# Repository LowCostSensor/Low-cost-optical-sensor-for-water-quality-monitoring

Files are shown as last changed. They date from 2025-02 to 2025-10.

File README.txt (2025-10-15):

Additional details on calibration and analytical performance:
Cirrone, R. G., Boldrini, A., Polvani, A., Arrigucci, M., Liu, X., Galgani, L., Woods, S., & Loiselle, S. A. (2025). Low-Cost Optical Sensing for Nitrate and Phosphate: Advancing Community Freshwater Monitoring. ACS ES&T Water.
https://doi.org/10.1021/acsestwater.5c00314

## License

This project is licensed under the GNU General Public License v3.0 (GPLv3).  
See the LICENSE file for details.

A portable, low-cost optical sensor for community-based monitoring of nitrates and orthophosphates in freshwater were developed. Its analytical performance and reliability were demonstrated in both laboratory conditions and the intended operational environment, with all components fully integrated. This achievement corresponds to a technological readiness level of 7-8. All necessary information for reproducing the sensor, including a 3D CAD model, software, and a user guide for setup and usage, has been made open-source. The same colorimetric kits employed in this study are currently utilized in 110 active citizen science projects across Europe and Africa. By improving the accuracy of these colorimetric kits, the proposed instrument has the potential to empower citizen science monitoring, breaking barriers to data integration between environmental agencies and community-driven monitoring. Nonetheless, further durability testing and inter-project validation could enhance the sensor’s reliability. Future work will focus on integrating fluorescence measurements, scattering correction, multispectral capabilities, and app-based functionality to expand the sensor’s applications and usability.

COMING SOON
Automatic data shared online.

For any information contact steven.loiselle@unisi.it // riccardogaetano.cirrone@unipa.it // amedeo.boldrini3@unisi.it // alessio.polvani@student.unisi.it

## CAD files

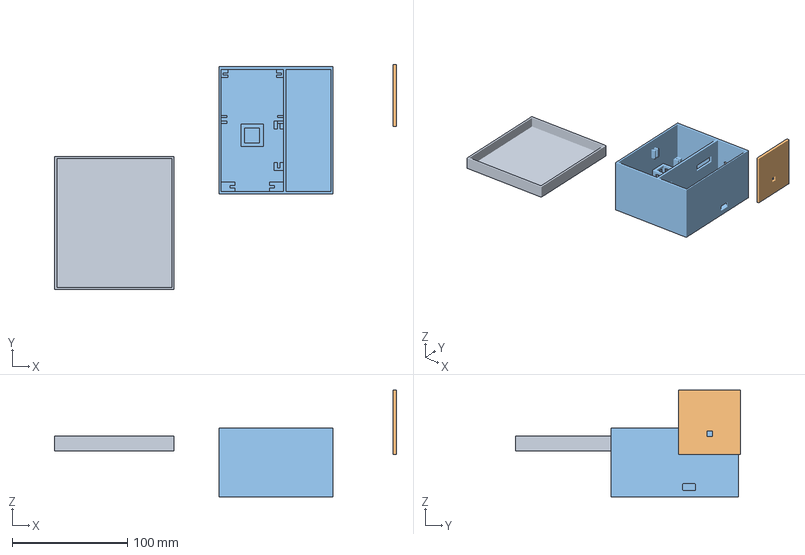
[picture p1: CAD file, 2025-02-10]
3D_CAD/Low_cost_optical_sensor_box_3D_CAD.3mf
297.3 x 196.0 x 92.8 mm
Cover
Fenditura
Main box

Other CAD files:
3D_CAD/Low_cost_optical_sensor_3D_CAD.stl

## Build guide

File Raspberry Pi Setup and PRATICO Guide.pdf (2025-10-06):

Raspberry Pi Terminal Setup & PRATICO Instrument Guide

1. First Boot and Login
- Connect Raspberry Pi to a monitor via mini HDMI and connect a keyboard.
- Power on the Raspberry Pi.
- Default login (Raspberry Pi OS):

Username: pi
Password: raspberry
- You will see the terminal prompt:

pi@raspberrypi:~$

2. Configure Wi-Fi using wpa_supplicant
1. Edit the wpa_supplicant file:

sudo nano /etc/wpa_supplicant/wpa_supplicant.conf
2. Add your network credentials:

country=US
ctrl_interface=DIR=/var/run/wpa_supplicant GROUP=netdev update_config=1

network={
ssid="YOUR_SSID"
psk="YOUR_PASSWORD"
}
3. Save (CTRL+O) and exit (CTRL+X).
4. Apply changes:

sudo wpa_cli reconfigure
5. Check your IP:

ip a

3. Enable SSH for Remote Access
1. Enable and start SSH:

sudo systemctl enable ssh
sudo systemctl start ssh
2. Find Pi’s IP:

hostname -I
3. Connect from another computer:

ssh pi@<IP_ADDRESS>

4. Wiring for FWW_user.py
- Green LED (light source): GPIO 26 -> Positive, GND -> Negative
- Red LED (working/not ready): GPIO 23 -> Positive, GND -> Negative
- Ready LED (green): GPIO 24 -> Positive, GND -> Negative
- Button: GPIO 4 -> Button -> GND
- I2C Sensor (LTR329): SDA -> SDA, SCL -> SCL, 3.3V -> VCC, GND -> GND
5. Python Script Overview (FWW_user.py and Calibration)
Purpose: Automates water analysis for N-NO3 and P-PO4 using LED light measurements and allows sensor calibration.
Initialization: - Setup GPIO, button, and I2C sensor. - Load calibration files (P_cal.txt,
N_cal.txt).
Key Functions: - lux_conversion(): Converts raw sensor data to lux. - LED_on(): Turns green LED on and records light readings. - simple_measure(): Measures ambient + LED light. -blank(): Blank measurement for reference. - measure(): Measures analyte sample. -concentration(): Converts absorbance to concentration. - save(): Saves results with timestamp. - Offline storage: Each measurement is automatically saved as a .txt file in /home/pa/ with a timestamp and analyte identifier (e.g., 2025_10_06_14_30_NNO3.txt). This allows offline access to results without network or database connection. - Nitrates() and Phosphates(): Handles analyte measurement logic. - NNO3_calibration() and PPO4_calibration(): Guides calibration using standard solutions. - linear_fitting(): Calculates calibration slope, intercept, and R^2. - main(): Controls loop and LED/button interactions.
Workflow: 1. Blank measurement at startup. 2. Loop: - Red LED blares. - Wait 10s for button press: - Pressed -> N-NO3 measurement. - Not pressed -> P-PO4 measurement. - Results are saved automatically offline as .txt files in /home/pa/. 3. Calibration guides user through known concentration standards and saves results to file.

6. ABC of Linux Terminal Commands Command Meaning
ls | List files
cd | Change directory
pwd | Print working directory
nano | Text editor
sudo | Execute as admin
chmod | Change file permissions
systemctl Manage services
reboot | Restart Pi
ip a | Show network interfaces
ssh | Secure remote login
7. Auto-run Script at Boot (Before Login)
1. Edit rc.local:

sudo nano /etc/rc.local
2. Add above exit 0:

python3 /home/pi/FWW_user.py &
3. Save and exit. The script will run on boot before login.
8. Python Requirements
Requirements.txt:

rpi.gpio
adafruit-circuitpython-ltr329-ltr303 numpy
pandas
scikit-learn
gpiozero
Installation (system-wide, no virtual environment):

sudo apt update
sudo apt install python3-pip -y
sudo pip3 install -r /home/pi/requirements.txt
This will install all required libraries for both the main instrument script and calibration script.

9. Move Files In/Out using SCP
Copy file from local machine to Raspberry Pi:

scp /path/to/local/file pi@<IP_ADDRESS>:/home/pi/
Copy file from Raspberry Pi to local machine:

scp pi@<IP_ADDRESS>:/home/pi/file.txt /path/to/local/destination/

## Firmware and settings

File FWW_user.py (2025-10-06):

"""
Author: Riccardo G. Cirrone
Last Update: Oct 2025

Field Guidelines for Water Analysis Instrument:
    1. Ensure calibration files (P_cal.txt and N_cal.txt) are present.
    2. Power on instrument; the green LED will turn on (ready for the blank).
    3. Press the button to perform the blank measurement (using distilled water).
    4. After the blank, the red LED will blink indicating the system is ready:
       - Wait 10 seconds without pressing --> P-PO4 mode
       - Press the button within 10 seconds --> N-NO3 mode
    5. In N-NO3 mode the green LED will blink
    6. Results are automatically saved to a timestamped .txt file
    7. After each measurement, the red LED blares again and the system is ready to choose the analyte again
"""

import time
import board
import adafruit_ltr329_ltr303 as adafruit_ltr329
import RPi.GPIO as GPIO
from datetime import datetime, timedelta
import pandas as pd
from gpiozero import Button as bt
import numpy as np
import threading

# --- Setup LEDs ---
GPIO.setmode(GPIO.BCM)
GPIO.setwarnings(False)
GPIO.setup(26, GPIO.OUT)  # Green LED (light source)
GPIO.setup(23, GPIO.OUT)  # Red LED (working/not ready)
GPIO.setup(24, GPIO.OUT)  # Green LED (ready)

# --- Setup button ---
button = bt(4, pull_up=True)
red_led_running = False
green_led_running = False

# --- Setup sensor ---
i2c = board.I2C()
time.sleep(0.5)
ltr329 = adafruit_ltr329.LTR329(i2c)

# --- Sensor parameters ---
ltr329.als_gain = 96
ALS_gain = ltr329.als_gain
ltr329.integration_time = 400
ALS_int = ltr329.integration_time
ltr329.measurement_rate = 2000
ALS_rate = ltr329.measurement_rate

print("WORKING PARAMETERS\n",
      f"GAIN = {ALS_gain}\n",
      f"Integration Time = {ALS_int}\n",
      f"Measurement Rate = {ALS_rate}\n")

# --- Load calibration ---
def get_calibration():
    P = open("/home/pa/P_cal.txt")
    P_content = P.readlines()
    P.close()
    P_R2 = float(P_content[6])
    P_slope = float(P_content[7])
    P_intercept = float(P_content[8])

    N = open("/home/pa/N_cal.txt")
    N_content = N.readlines()
    N.close()
    N_R2 = float(N_content[6])
    N_slope = float(N_content[7])
    N_intercept = float(N_content[8])

    return P_R2, P_slope, P_intercept, N_R2, N_slope, N_intercept

P_R2, P_slope, P_intercept, N_R2, N_slope, N_intercept = get_calibration()

# --- Global variables ---
values = []
blank_value = []

# --- Lux conversion ---
def lux_conversion():
    CH0, CH1 = ltr329.light_channels
    try:
        ratio = CH1 / (CH0 + CH1 + 1e-7)  # avoid division by zero
        if ratio < 0.45:
            ALS_lux = (1.7743 * CH0 + 1.1059 * CH1) / ALS_gain / ALS_int
        elif 0.45 <= ratio < 0.64:
            ALS_lux = (4.2785 * CH0 - 1.9548 * CH1) / ALS_gain / ALS_int
        elif 0.64 <= ratio < 0.85:
            ALS_lux = (0.5926 * CH0 + 0.1185 * CH1) / ALS_gain / ALS_int
        else:
            ALS_lux = 1e-5
    except ZeroDivisionError:
        ALS_lux = 0
    return ALS_lux

# --- LED control ---
def LED_on():
    GPIO.output(26, GPIO.HIGH)
    stop = datetime.now() + timedelta(seconds=2)
    while datetime.now() <= stop:
        lux = round(lux_conversion(),4)
        print(lux)
        values.append(lux)
        time.sleep(0.5)
    GPIO.output(26, GPIO.LOW)

def passive():
    stop = datetime.now() + timedelta(seconds=3)
    while datetime.now() <= stop:
        lux = round(lux_conversion(),4)
        print(lux)
        values.append(lux)
        time.sleep(0.5)

def simple_measure():
    passive()
    LED_on()
    passive()

# --- LED blinking ---
def ready_on():
    GPIO.output(24, GPIO.HIGH)

def ready_off():
    GPIO.output(24, GPIO.LOW)

def working_on():
    GPIO.output(23, GPIO.HIGH)

def working_off():
    GPIO.output(23, GPIO.LOW)

def blare_red():
    global red_led_running
    red_led_running = True
    while red_led_running:
        GPIO.output(23, GPIO.HIGH)
        time.sleep(0.5)
        GPIO.output(23, GPIO.LOW)
        time.sleep(0.5)

def stop_blare_red():
    global red_led_running
    red_led_running = False

def blare_green():
    global green_led_running
    green_led_running = True
    while green_led_running:
        GPIO.output(24, GPIO.HIGH)
        time.sleep(0.5)
        GPIO.output(24, GPIO.LOW)
        time.sleep(0.5)

def stop_blare_green():
    global green_led_running
    green_led_running = False

# --- Measurement functions ---
def blank():
    ready_on()
    button.wait_for_press()
    ready_off()
    working_on()
    simple_measure()
    working_off()
    try:
        b = max(values)
    except ValueError:
        b = 0
    blank_value.append(b)
    values.clear()

def measure():
    stop_blare_red()
    stop_blare_green()
    time.sleep(0.5)
    ready_on()
    button.wait_for_press()
    ready_off()
    working_on()
    simple_measure()
    working_off()
    try:
        A = round(-np.log10((max(values)-0.0004)/(max(blank_value)-0.0004)),4)
    except (ZeroDivisionError, ValueError):
        A = 0
    values.clear()
    GPIO.output(26, GPIO.LOW)
    return A

def concentration(absorbance, analyte):
    if analyte == 'N':
        if N_slope != 0:
            c = (absorbance - N_intercept) / N_slope
        else:
            c = 0
    elif analyte == 'P':
        if P_slope != 0:
            c = (absorbance - P_intercept) / P_slope
        else:
            c = 0
    return c

def save(conc, analyte):
    conc_str = str(conc) + " " + analyte + " (mg/L)"
    half_path = "/home/pa/"
    timestamp = datetime.now().strftime("%Y_%m_%d_%H_%M")
    path = f"{half_path}{timestamp}_{analyte}.txt"
    with open(path,"w") as f:
        f.write(conc_str)

# --- Analysis ---
def Nitrates():
    stop_blare_red()
    t2 = threading.Thread(target=blare_green)
    t2.start()
    absorbance = measure()
    result = concentration(absorbance, 'N')
    save(result, 'NNO3')
    stop_blare_green()

def Phosphates():
    stop_blare_red()
    absorbance = measure()
    result = concentration(absorbance, 'P')
    save(result, 'PPO4')

# --- Main control ---
def main():
    while True:
        t = threading.Thread(target=blare_red)
        t.start()
        stop_time = datetime.now() + timedelta(seconds=10)
        while datetime.now() <= stop_time:
            if button.is_pressed:
                Nitrates()
                break
            time.sleep(0.05)
        else:
            Phosphates()
        time.sleep(1)

# --- Run ---
if __name__ == "__main__":
    blank()
    main()

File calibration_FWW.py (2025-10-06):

"""
Author: Riccardo G. Cirrone
Last update: Oct 2025

Calibration script for PRATICO sensor.
For on-field analysis, use FWW.py (see User's guide).
"""

import time
import board
import adafruit_ltr329_ltr303 as adafruit_ltr329
import RPi.GPIO as GPIO
from datetime import datetime, timedelta
import numpy as np
from sklearn.linear_model import LinearRegression

# Paths to save calibration results
N_path = "/home/pa/N_cal.txt"
P_path = "/home/pa/P_cal.txt"

# Setup GPIO
GPIO.setmode(GPIO.BCM)
GPIO.setup(26, GPIO.OUT)

# Setup sensor
i2c = board.I2C()
time.sleep(0.5)
ltr329 = adafruit_ltr329.LTR329(i2c)

# Sensor parameters
ltr329.als_gain = 96
ALS_gain = ltr329.als_gain
ltr329.integration_time = 400
ALS_int = ltr329.integration_time
ltr329.measurement_rate = 2000
ALS_rate = ltr329.measurement_rate

print("Working parameters:\n",
      f"Gain = {ALS_gain}\n",
      f"Integration time = {ALS_int}\n",
      f"Measurement rate = {ALS_rate}\n")

# Temporary storage
values = []
N_abs = []
P_abs = []

# Standard solution concentrations
N = [0.2, 0.5, 1, 2, 5, 10]  # ppm
P = [0.02, 0.05, 0.1, 0.2, 0.5, 1]  # ppm

# --- Functions ---

def lux_conversion():
    CH0, CH1 = ltr329.light_channels
    try:
        ratio = CH1 / (CH0 + CH1)
        if ratio < 0.45:
            ALS_lux = (1.7743 * CH0 + 1.1059 * CH1) / ALS_gain / ALS_int
        elif 0.45 <= ratio < 0.64:
            ALS_lux = (4.2785 * CH0 - 1.9548 * CH1) / ALS_gain / ALS_int
        elif 0.64 <= ratio < 0.85:
            ALS_lux = (0.5926 * CH0 + 0.1185 * CH1) / ALS_gain / ALS_int
        else:
            ALS_lux = 1e-5
    except ZeroDivisionError:
        ALS_lux = 0
    return ALS_lux

def LED_on():
    values.clear()
    GPIO.output(26, GPIO.HIGH)
    stop = datetime.now() + timedelta(seconds=2)
    while datetime.now() <= stop:
        lux = round(lux_conversion(), 4)
        values.append(lux)
        print(lux)
        time.sleep(0.5)
    GPIO.output(26, GPIO.LOW)

def passive():
    values.clear()
    stop = datetime.now() + timedelta(seconds=3)
    while datetime.now() <= stop:
        lux = round(lux_conversion(), 4)
        values.append(lux)
        print(lux)
        time.sleep(0.5)

def measure():
    passive()
    LED_on()
    passive()

def blank():
    # Lasciata invariata come richiesto
    measure()
    b = max(values) if values else 1e-5
    values.clear()
    return b

def linear_fitting(a, b):
    lr = LinearRegression()
    X = np.array(a).reshape(-1, 1)
    y = np.array(b)
    lr.fit(X, y)
    R2 = round(lr.score(X, y), 4)
    slope = lr.coef_[0]
    intercept = lr.intercept_
    return R2, slope, intercept

def NNO3_calibration(b):
    print("Calibrating for N-NO3 (ppm): 0.2, 0.5, 1, 2, 5, 10")
    for conc in N:
        input(f"Insert N-NO3 standard solution at {conc} mg/L and press Enter...")
        measure()
        try:
            A = round(-np.log10((max(values)-0.0004)/(max(b)-0.0004)),4)
        except ZeroDivisionError:
            A = 0
        N_abs.append(A)
    print("Calibrating...")
    R2, slope, intercept = linear_fitting(N, N_abs)
    print(f">>> N-NO3 Calibration Results:\nR^2 = {R2}\nSlope = {slope}\nIntercept = {intercept}\n")
    with open(N_path, "w") as f:
        f.write(f"N-NO3 calibration results:\nR^2 = {R2}\nSlope = {slope}\nIntercept = {intercept}\n")

def PPO4_calibration(b):
    print("Calibrating for P-PO4 (ppm): 0.02, 0.05, 0.1, 0.2, 0.5, 1")
    for conc in P:
        input(f"Insert P-PO4 standard solution at {conc} mg/L and press Enter...")
        measure()
        try:
            A = round(-np.log10((max(values)-0.0004)/(max(b)-0.0004)),4)
        except ZeroDivisionError:
            A = 0
        P_abs.append(A)
    print("Calibrating...")
    R2, slope, intercept = linear_fitting(P, P_abs)
    print(f">>> P-PO4 Calibration Results:\nR^2 = {R2}\nSlope = {slope}\nIntercept = {intercept}\n")
    with open(P_path, "w") as f:
        f.write(f"P-PO4 calibration results:\nR^2 = {R2}\nSlope = {slope}\nIntercept = {intercept}\n")

# --- Main ---

input(">>> Insert the blank sample and press Enter...")
blank_value = blank()

while True:
    try:
        choice = input("Choose calibration: NNO3 or PPO4 (N/P) --> ").lower()
        if choice == 'n':
            NNO3_calibration(blank_value)
            break
        elif choice == 'p':
            PPO4_calibration(blank_value)
            break
        else:
            print("Invalid choice. Enter 'N' or 'P'.")
    except Exception as e:
        print("Error:", e)
